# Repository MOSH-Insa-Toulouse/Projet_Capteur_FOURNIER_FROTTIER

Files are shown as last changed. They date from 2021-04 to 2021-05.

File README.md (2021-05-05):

# Projet_Capteur_FOURNIER_FROTTIER
Acquisition chain to characterize graphite sensor

# Sommaire

1) Introduction
2) Code Arduino
3) Shield PCB
4) APK
5) Banc de test et mesures
6) Pistes d'amélioration
7) Contacts

# Introduction

Le capteur de déformation est constitué d'un morceau de papier sur lequel on dépose du graphite en coloriant avec un crayon à papier. Les particules de graphite forment alors un système granulaire. Ainsi lorsqu'on plie légèrement le papier, les particules s'éloignent ou se rapprochent les unes des autres (dépend du sens dans lequel on le plie). Dans le cas d'une compression (rapprochement des particules) l'effet tunnel fait qu'il y a plus d'électrons qui arrivent à passer d'une particule à une autre. Dans le cas d'une extension (éloignement des particules) c'est l'inverse qui se produit. Ainsi dans un cas la résistance diminue et dans l'autre cas elle augmente. Nous pouvons mesurer cette variation de résistance en mesurant la variation de courant. Ce capteur étant passif, il faut le conditionner. Pour cela nous introduisons un circuit transimpédance qui amplifie le courant mesuré et le convertit en tension. C'est cette tension qui est ensuite lue par l'entrée analogique de la carte Arduino.

# Code Arduino

Le code Arduino réalise la lecture analogique du signal amplifié sur l'entrée analogique A0 et convertit les valeurs analogiques en valeurs numériques (octets). Il permet également l'envoie des données octet par octet au module Bluetooth HC05. Sachant que ces données sont ensuite transmises par Bluetooth à l'APK, nous avons pris soin d'imposer la fréquence d'envoie des données (envoie d'un octet toutes les 200 ms, fréquence correspondant à celle de la clock de l'APK). Ainsi chaque octet envoyé est directement lu par l'APK sans delay. Ce code réalise aussi la communication avec l'écran OLED. Notez que pour cela il vous faut ajouter les librairies suivantes à votre code : Adafruit_GFX.h et Adafruit_SSD1306.h. Vous aurez aussi besoin de l'adresse d l'OLED (ici 0x3C). Notre fonction void LED() gère l'affichage de la tension Vadc en Volt (lue sur l'entrée A0) ainsi que le calcul et l'affichage de la résistance du capteur en MOhm.

# Shield PCB

Le shield a été réalisé sur le logiciel Kicad puis imprimé à l'Atelier d'électronique de l'INSA Toulouse. Nous y avons mis un circuit transimpédance afin d'amplifier le courant généré par le capteur et le convertir en tension. Nous y avons également pluggé le module Bluetooth HC05, l'écran OLED et un servomoteur (voir partie 5 Banc de test et mesures).

# APK

L'application Android a été réalisée via le site web MIT App Inventor. Elle communique avec le module Bluetooth de votre smartphone pour se connecter au module HC05 et recevoir des données. Pour cela, l'utilisateur n'a qu'à cliquer sur "Bluetooth" et choisir le module HC05 parmi la liste qui s'affiche. Une fois la connexion établie, l'application lit les données reçues par le smartphone et les affiche. On voit donc s'afficher à l'écran la valeur numérique de la tension Vadc en Volt et sa courbe sur un graphique. L'application calcule également la valeur de la résistance du capteur à partir de Vadc et des valeurs des résistances du montage transimpédance. La valeur numérique de la résistance est ensuite affichée sur l'écran.

# Banc de test et mesures

Afin d'échantillonner notre capteur, nous avons conçu un banc de test permettant d'obtenir la résistance du capteur pour un grand nombre de courbures différentes. Le banc a été conçu sous SoliWorks et imprimé en PLA à l'aide d'une imprimante 3D. En faisant tourner un servomoteur contrôlé par le programme Arduino, nous pouvons ainsi mesurer la résistance du capteur pour des angles de courbure précis et un grand nombre de fois. En laissant le moteur faire des va-et-vient plusieurs minutes nous nous retrouvons rapidement avec plusieurs milliers de points dans le Serial Monitor. Il suffit ensuite de copier ces données dans un nouveau fichier texte dans le même dossier que le programme Python. En modifiant le nom du fichier texte à traiter dans le code puis en l'exécutant on obtient un nuage de point des valeurs de résistance en fonction de l'angle de courbure. On observe que pour un certain intervalle d'angle, la résistance décroit linéairement avec la déformation (voir courbes dans la datasheet). A noter que le type de graphite (2H, 2B, HB ...) influence la variation de résistance.

# Limites et pistes d'améliorations

La principale limite de ce capteur est qu'il a une zone de non détérioration très restreinte (dépend du type de graphite mais généralement pas plus de 45°). Il va fonctionner pour de faibles déformations seulement. Si la déformation est trop importante, on endommage le capteur et la résistance ne varie plus linéairement. Un autre problème est qu'il est très difficile d'obtenir un signal stable. Même en maintenant la déformation constante, la résistance varie et on n'obtient jamais les mêmes valeurs d'une acquisition à une autre. C'est pour cette raison que nous avons fait un grand nombre de mesures. Le capteur est trop sensible et le courant mesuré dépend de trop de paramètres (l'expérimentateur, l'épaisseur de graphite, l'humidité, la pression, le contact des broches métalliques ...). Enfin on est limité par la résistance de gain du montage transimpédance. Pour certains types de graphite, le signal observé est trop faible, alors que pour d'autres, il sature. Une piste d'amélioration serait de mettre un connecteur sur le shield à la place de la résistance de gain, afin de pouvoir changer facilement la résistance et ainsi adapter le rapport d'amplification.

# Contacts

Ce projet a été réalisé par 2 étudiants de département Génie Physique de l'INSA Toulouse :
Théo Frottier : tfrottie@etud.insa-toulouse.fr
Tom Fournier : tfournie@etud.insa-toulouse.fr

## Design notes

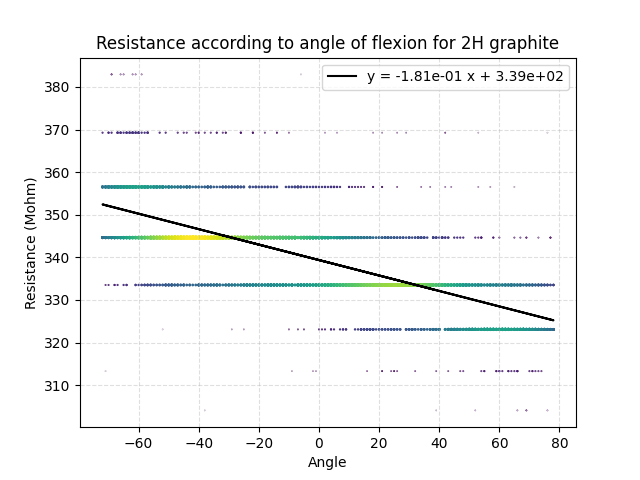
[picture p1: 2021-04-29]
Data processing - Python/2H linear part.png

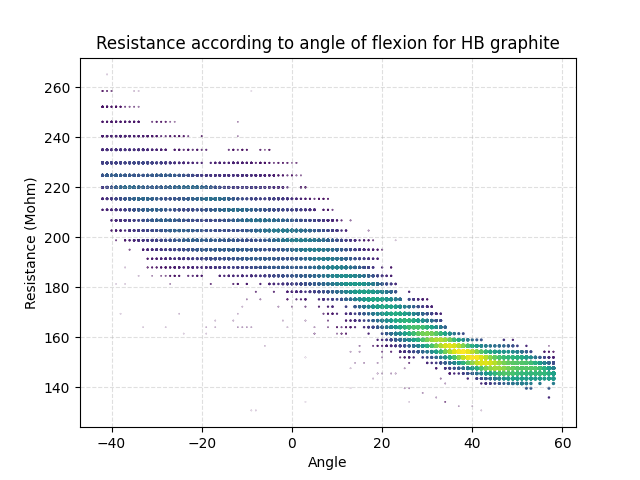
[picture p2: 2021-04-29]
Data processing - Python/HB wide angle.png

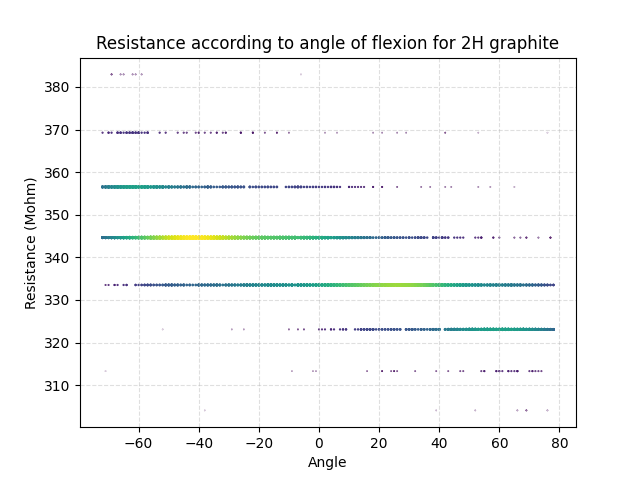
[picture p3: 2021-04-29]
Data processing - Python/2H wide angle.png

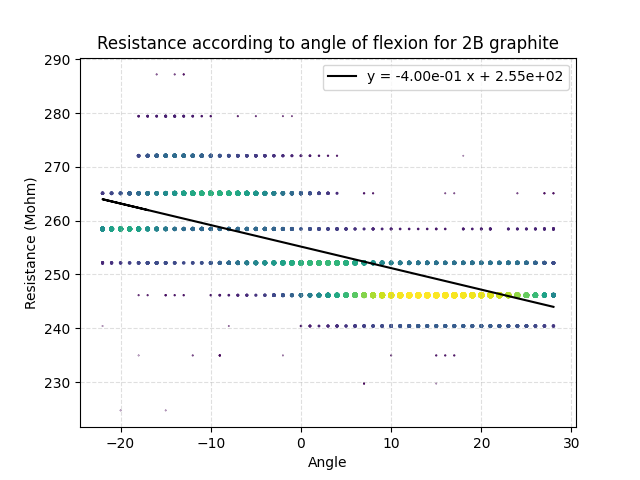
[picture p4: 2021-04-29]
Data processing - Python/2B linear part.png

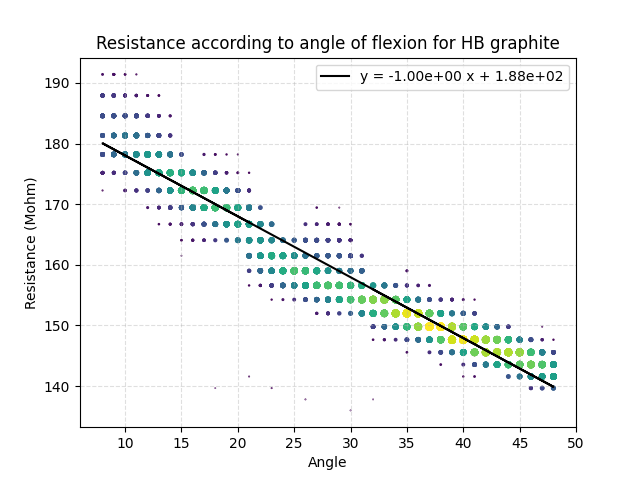
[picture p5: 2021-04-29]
Data processing - Python/HB linear part.png

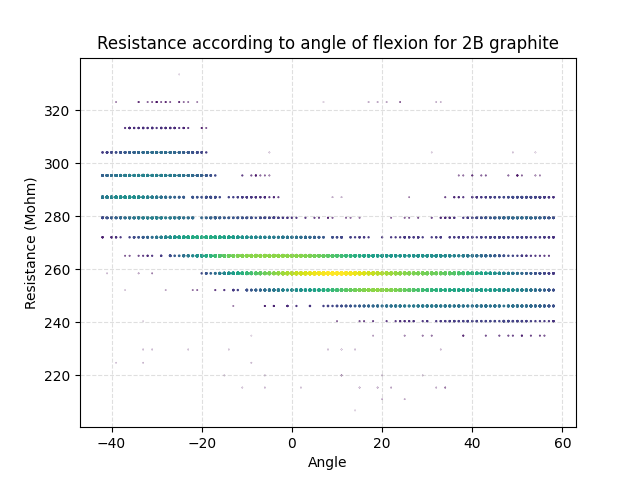
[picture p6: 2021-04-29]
Data processing - Python/2B wide angle.png

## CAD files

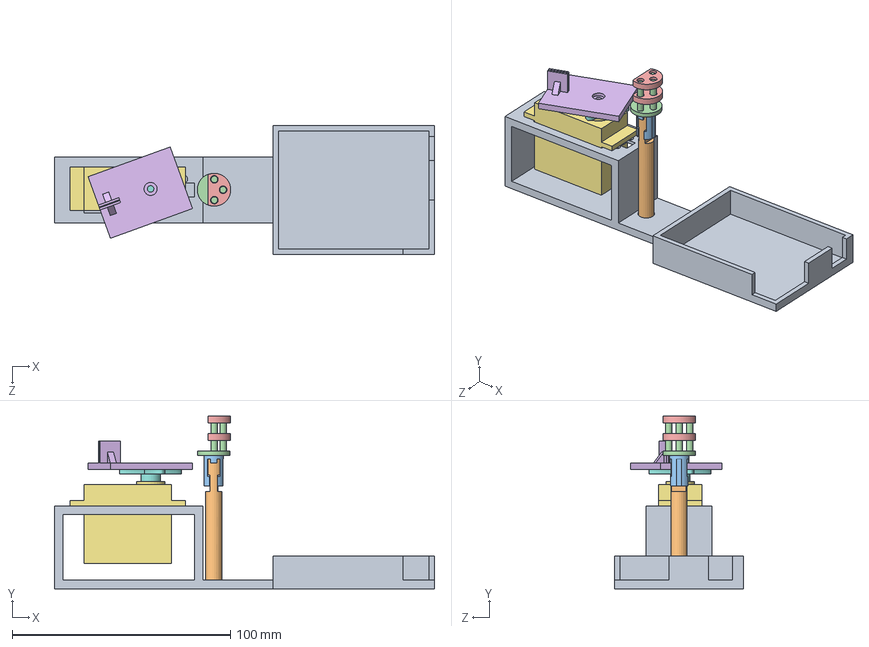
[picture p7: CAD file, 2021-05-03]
Test bench - SW Arduino APK/3D printing/Assembly.SLDASM
174.0 x 79.0 x 59.0 mm
Banc de test
Pililer
Clips
Support pinces
Shift x 2
Extension servo
Servomoteur
Hélice servomoteur

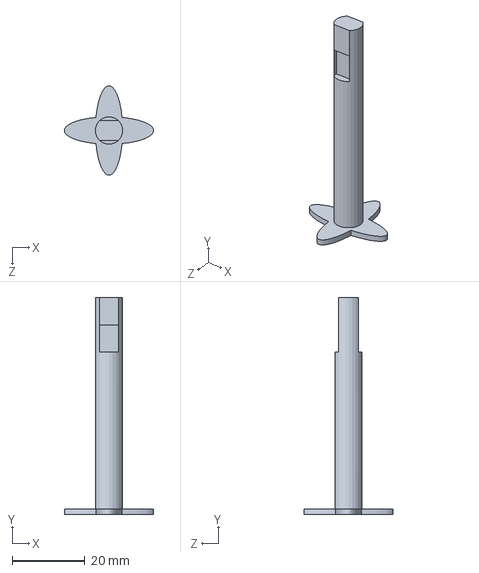
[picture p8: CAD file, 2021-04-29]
Test bench - SW Arduino APK/3D printing/Parts/Pililer.SLDPRT
24.5 x 59.5 x 24.5 mm

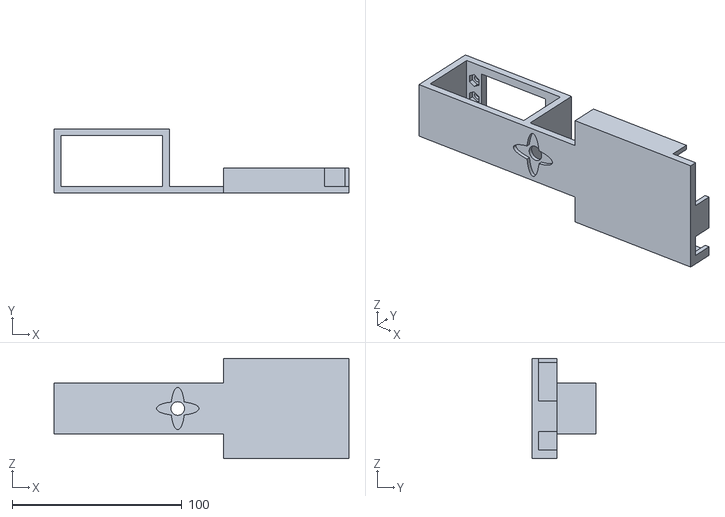
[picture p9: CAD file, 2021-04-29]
Test bench - SW Arduino APK/3D printing/Parts/STL files/Banc de test v2.STL
174.0 x 38.0 x 59.0

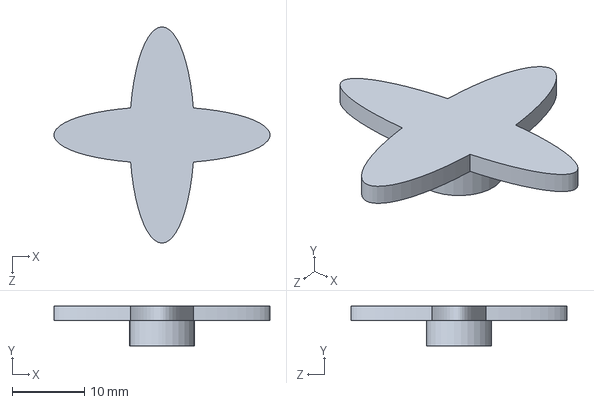
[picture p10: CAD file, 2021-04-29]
Test bench - SW Arduino APK/3D printing/Parts/Hélice servomoteur.SLDPRT
30.0 x 5.50 x 30.0 mm

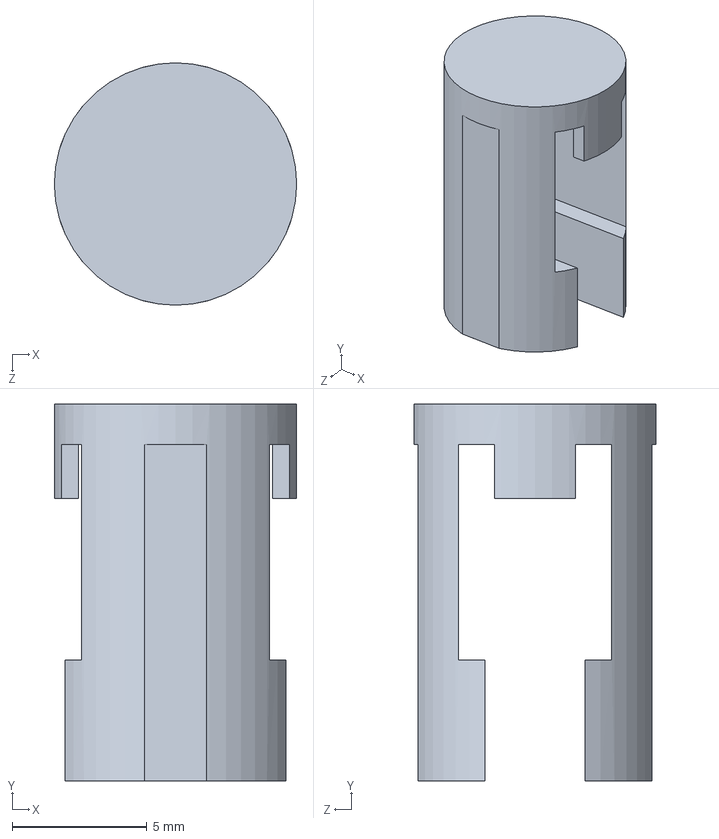
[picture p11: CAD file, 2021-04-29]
Test bench - SW Arduino APK/3D printing/Parts/Clips.SLDPRT
9.00 x 14.0 x 9.00 mm

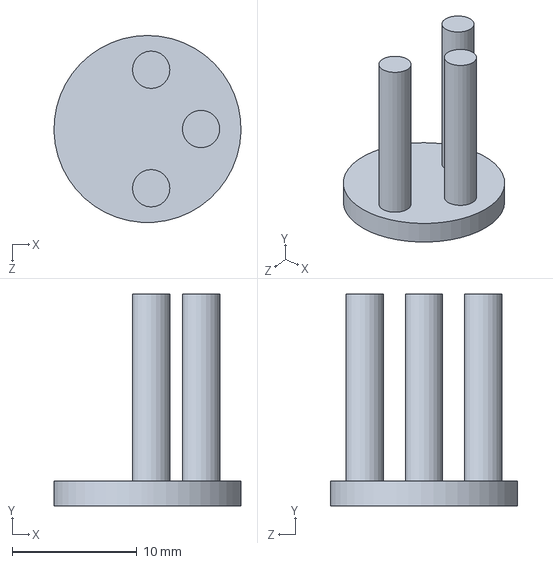
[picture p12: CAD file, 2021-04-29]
Test bench - SW Arduino APK/3D printing/Parts/Support pinces.SLDPRT
15.0 x 17.0 x 15.0 mm

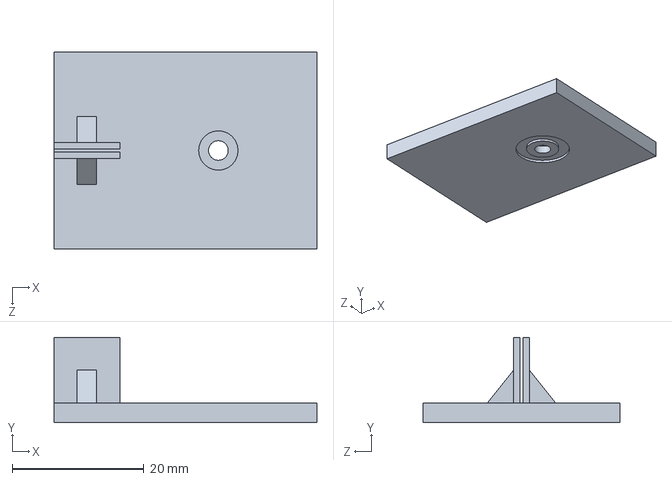
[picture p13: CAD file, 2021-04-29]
Test bench - SW Arduino APK/3D printing/Parts/Extension servo.SLDPRT
40.0 x 13.0 x 30.0 mm

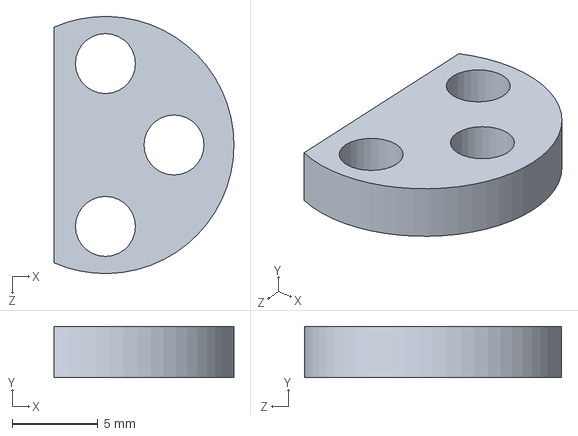
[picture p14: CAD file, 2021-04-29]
Test bench - SW Arduino APK/3D printing/Parts/Shift.SLDPRT
10.5 x 3.00 x 15.0 mm

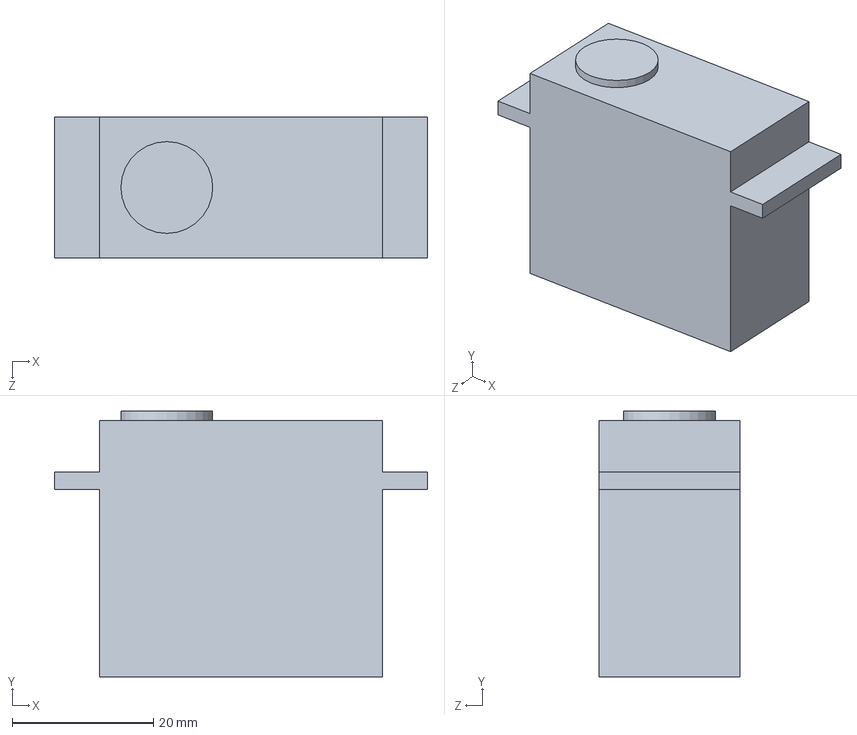
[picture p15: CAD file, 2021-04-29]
Test bench - SW Arduino APK/3D printing/Parts/Servomoteur.SLDPRT
52.8 x 37.6 x 20.0 mm

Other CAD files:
Test bench - SW Arduino APK/3D printing/Parts/Banc de test.SLDPRT
Test bench - SW Arduino APK/3D printing/Parts/STL files/Clips.STL
Test bench - SW Arduino APK/3D printing/Parts/STL files/Extension servo.STL
Test bench - SW Arduino APK/3D printing/Parts/STL files/Pililer.STL
Test bench - SW Arduino APK/3D printing/Parts/STL files/Shift.STL
Test bench - SW Arduino APK/3D printing/Parts/STL files/Support pinces.STL

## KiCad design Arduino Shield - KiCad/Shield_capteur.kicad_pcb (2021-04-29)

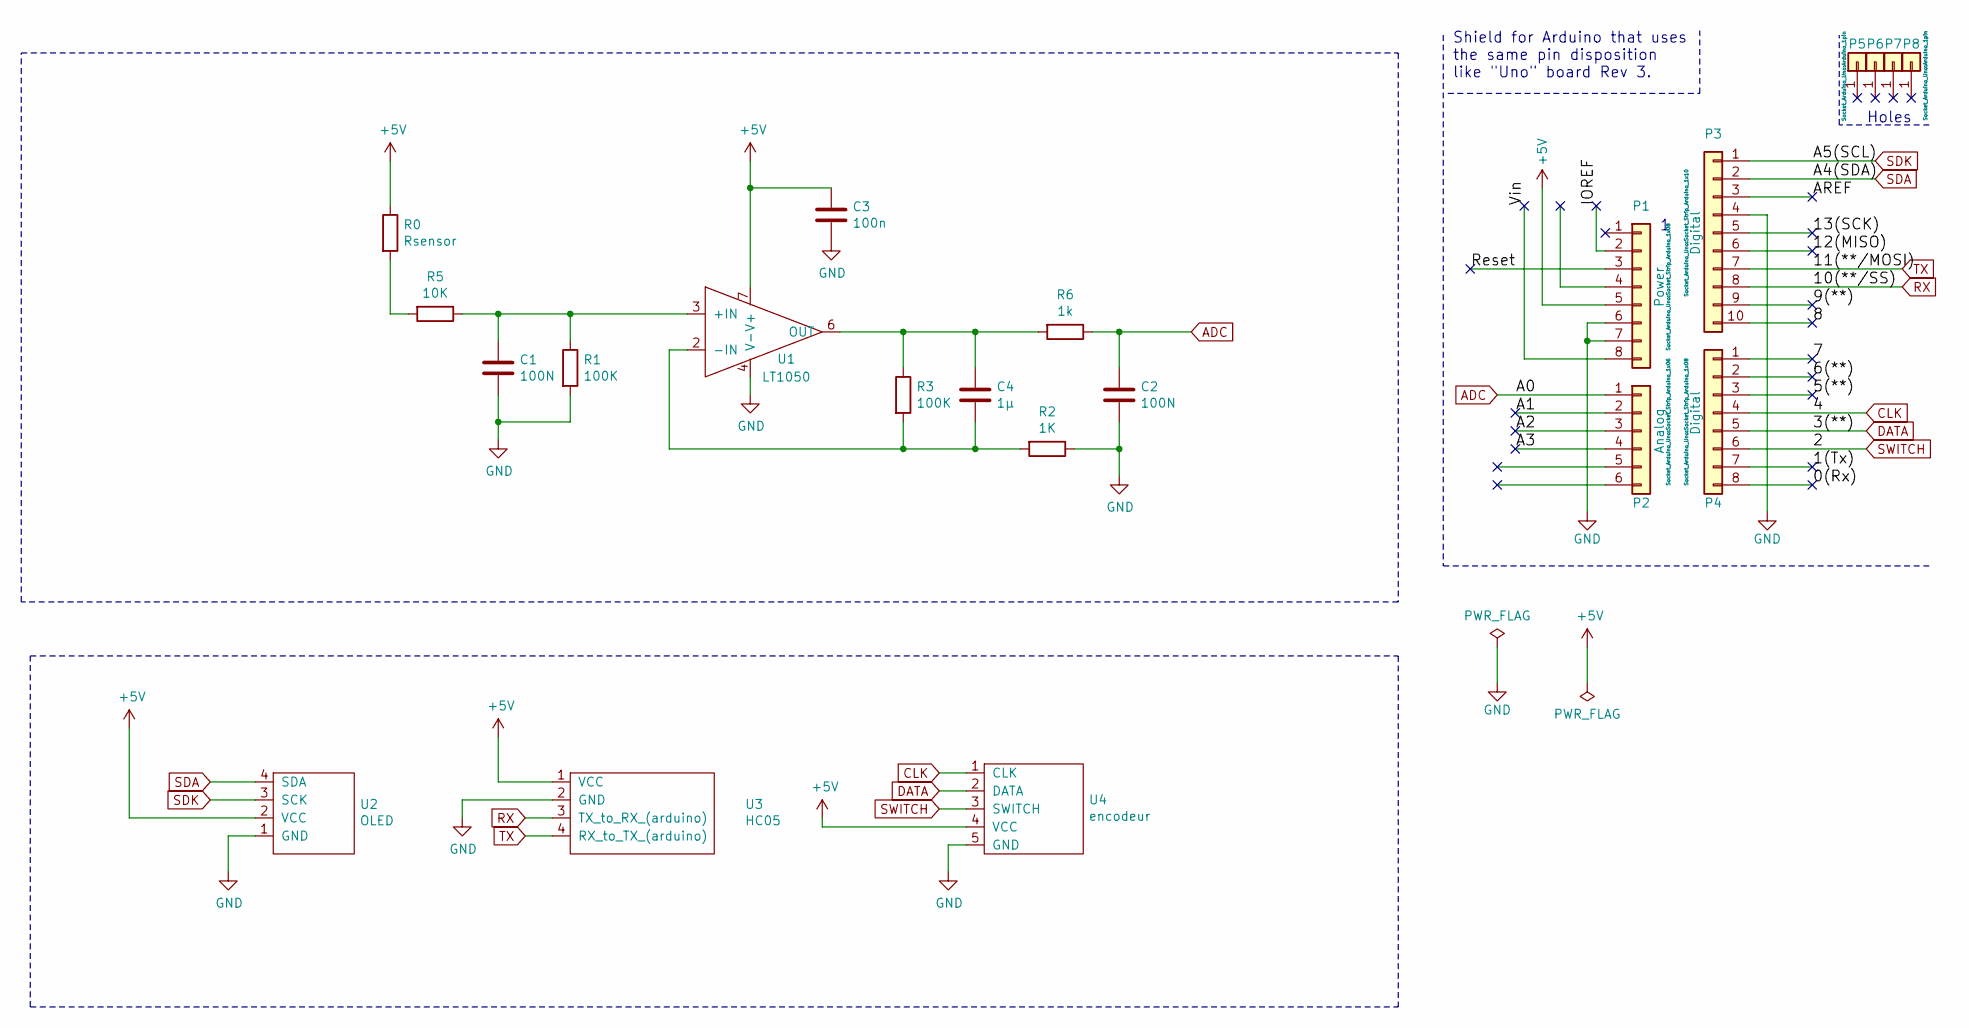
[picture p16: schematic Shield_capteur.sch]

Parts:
C1, C2: 100N; Composant
C3: 100n; Composant
C4: 1µ; Composant
P1: Power; Socket_Strip_Arduino_1x08
P2: Analog; Socket_Strip_Arduino_1x06
P3: Digital; Socket_Strip_Arduino_1x10
P4: Digital; Socket_Strip_Arduino_1x08
P5, P6, P7, P8: CONN_01X01; Arduino_1pin
R0: Rsensor; Sensor
R1, R3: 100K; Composant
R2: 1K; Composant
R5: 10K; Composant
R6: 1k; Composant
U1: LT1050; Microcontroler
U2: OLED
U3: HC05; Bluetooth
U4: encodeur; Encodeur

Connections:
+5V: C3.1, P1.5, R0.1, U1.7 (V+), U2.2 (VCC), U3.1 (VCC), U4.4 (VCC)
/0(Rx): P4.8
/1(Tx): P4.7
/5(**): P4.3
/6(**): P4.2
/7: P4.1
/8: P3.10
/9(**): P3.9
/12(MISO): P3.6
/13(SCK): P3.5
/A1: P2.2
/A2: P2.3
/A3: P2.4
/AREF: P3.3
/IOREF: P1.2
/Reset: P1.3
/Vin: P1.8
ADC: C2.1, P2.1, R6.1
CLK: P4.4, U4.1 (CLK)
DATA: P4.5, U4.2 (DATA)
GND: C1.2, C2.2, C3.2, P1.6, P1.7, P3.4, R1.2, R2.1, U1.4 (V-), U2.1 (GND), U3.2 (GND), U4.5 (GND)
IN+: C1.1, R1.1, R5.1, U1.3 (+IN)
IN-: C4.2, R2.2, R3.2, U1.2 (-IN)
unnamed: C4.1, R3.1, R6.2, U1.6 (OUT)
unnamed: R0.2, R5.2
RX: P3.8, U3.3 (TX_to_RX_(arduino))
SDA: P3.2, U2.4 (SDA)
SDK: P3.1, U2.3 (SCK)
SWITCH: P4.6, U4.3 (SWITCH)
TX: P3.7, U3.4 (RX_to_TX_(arduino))

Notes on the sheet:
Holes
Shield for Arduino that uses the same pin disposition like "Uno" board Rev 3.

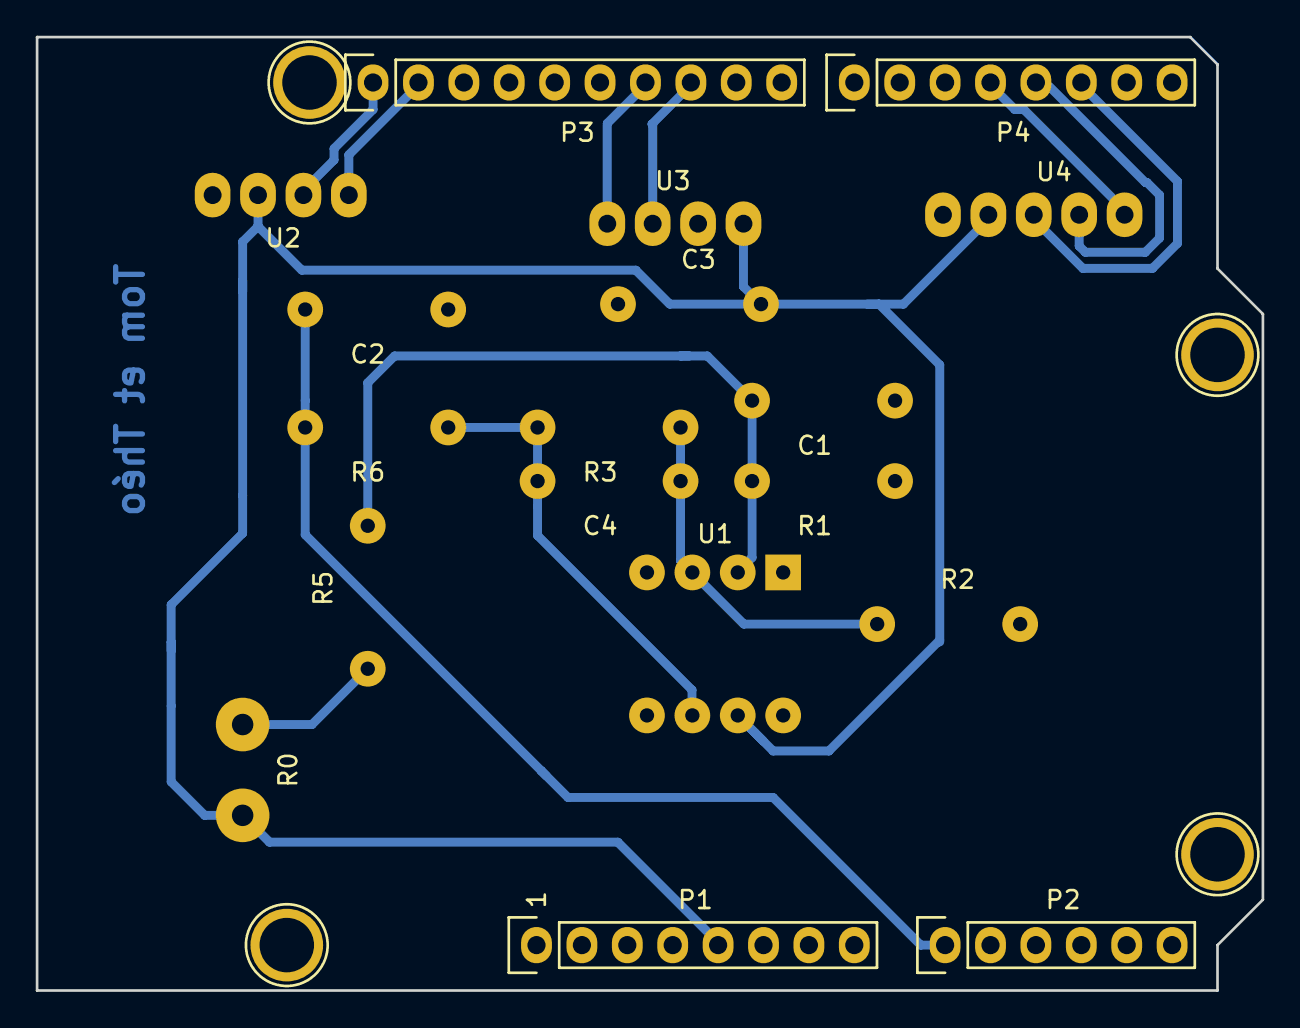
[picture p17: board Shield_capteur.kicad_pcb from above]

Board: 2 copper layers, 68.6 x 53.3 mm, 22 parts (0 on the bottom side), 14 nets.

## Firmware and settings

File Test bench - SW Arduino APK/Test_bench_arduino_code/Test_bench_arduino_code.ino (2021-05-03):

#include <Servo.h>
#include <SPI.h>
#include <Wire.h>
#include <Adafruit_GFX.h>
#include <Adafruit_SSD1306.h>
#include <SoftwareSerial.h>
#define PERIODE 200
#define rxPin 10 
#define txPin 11 
SoftwareSerial HC05(rxPin ,txPin); 

#define SCREEN_WIDTH 128
#define SCREEN_HEIGHT 64

Adafruit_SSD1306 display(SCREEN_WIDTH, SCREEN_HEIGHT, &Wire, -1);

int pos = 0;
float fake_pos = 0;
int pos_max = 0;
int pos_min = 0;
float res;
float tension;
float Vcc = 5.0;
float R5 = 10.0*pow(10,3);
float R1 = 100.0*pow(10,3);
float R2 = 1.0*pow(10,3);
float R3 = 100.0*pow(10,3);

Servo myservo;

 
void setup() {
  Serial.begin(9600);  
  myservo.attach(2);

  //HC05
  pinMode(rxPin, INPUT);
  pinMode(txPin, OUTPUT);
  HC05.begin(9600);
  
  //OLED
  if(!display.begin(SSD1306_SWITCHCAPVCC, 0x3C)) { // Address 0x3D for 128x64
    Serial.println(F("SSD1306 allocation failed"));
    for(;;);
  }
  delay(2000);
  display.clearDisplay();
  display.println("Init., pls wait.");
  display.display(); 
  delay(2000);
  LED();
}


void measure(){
  fake_pos = pos;
  delay(50); 
  Serial.print(fake_pos); 
  Serial.print(" ");                                   
  Serial.println(analogRead(A0));
  delay(50); 
  Serial.print(fake_pos); 
  Serial.print(" ");                                   
  Serial.println(analogRead(A0));
  delay(50); 
  Serial.print(fake_pos); 
  Serial.print(" ");                                   
  Serial.println(analogRead(A0));
}

void LED(){
  tension = analogRead(A0)/1024.0*5.0;
  res = abs(((R1/R2)*((R2+R3)*Vcc)/tension)-R1-R5);
  display.clearDisplay();
  display.setTextSize(1);
  display.setTextColor(WHITE);
  display.setCursor(0, 10);
  display.print("U : ");
  display.print(tension);
  display.println(" V");
  display.println(" ");
  display.print("R : ");
  display.print(res/1000.0/1000.0);
  display.print(" Mohm");
  display.display();
}

void BT(){
  HC05.write(map(analogRead(A0),0,1024,0,255));
}

void loop() {
  
  pos_max = 150;
  pos_min = 20;
  
   for (pos = pos_min; pos <= pos_max; pos += 1) { 
    myservo.write(pos);           
    measure();
    LED();
    BT();
  }
  
  for (pos = pos_max; pos >= pos_min; pos -= 1) { 
    myservo.write(pos);          
    measure();
    LED();
    BT();
  }
  
}
